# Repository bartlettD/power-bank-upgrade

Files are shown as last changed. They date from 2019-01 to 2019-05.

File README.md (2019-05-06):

# Power Bank Upgrade

A replacement PCB for a cheap single cell power bank.

Designed with KiCad 5.0.2

PDF Schematics, Gerbers and Images are available in the "Docs" directory.

<p float="center">
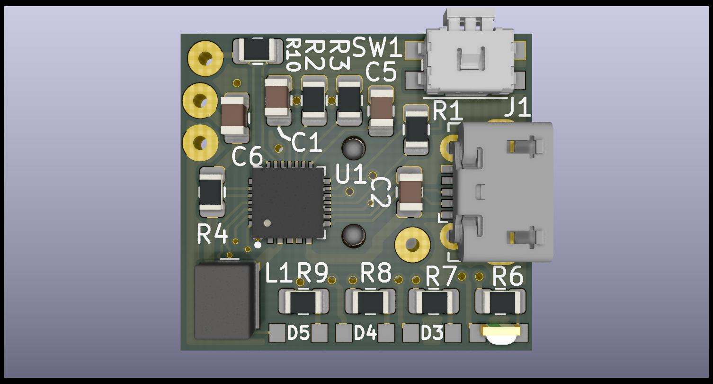
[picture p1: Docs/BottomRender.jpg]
    
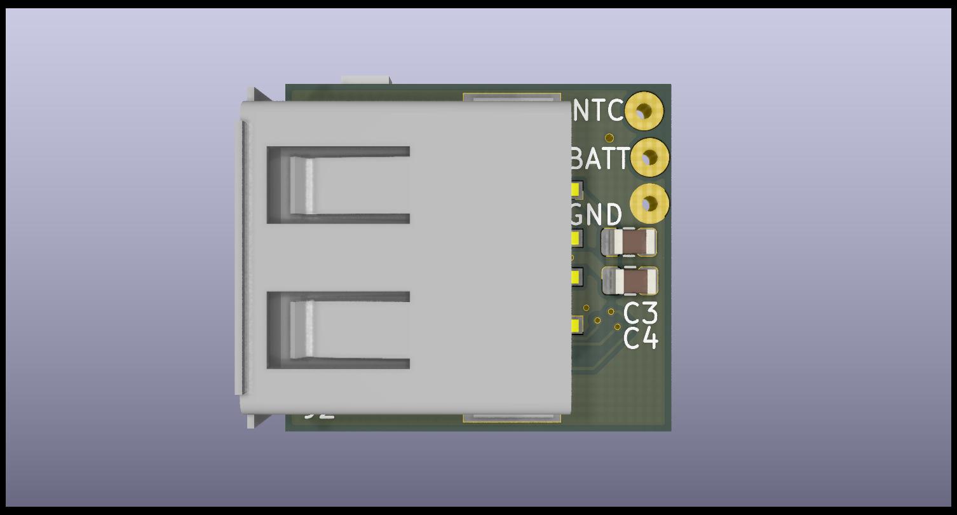
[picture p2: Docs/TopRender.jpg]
    
</p>

## Introduction

This is a single cell, Li-Ion USB Power bank based around an Monolithic Power 
Solutions MP2632B IC.

The board was designed to be broadly compatible with the plastics from a common
model of power bank available from Pound shops except with a few extra features.

## Features

* 3000 mAh LG HG2 Cell. 250% more capacity!
* State of Charge LED indicator.
* Faster Charge and Discharge Currents. (3A)
* Thermistor Thermal Regulation and Shutdown.
* Will actually charge a modern smartphone.

## Licence
The project is licenced under the MIT licence.

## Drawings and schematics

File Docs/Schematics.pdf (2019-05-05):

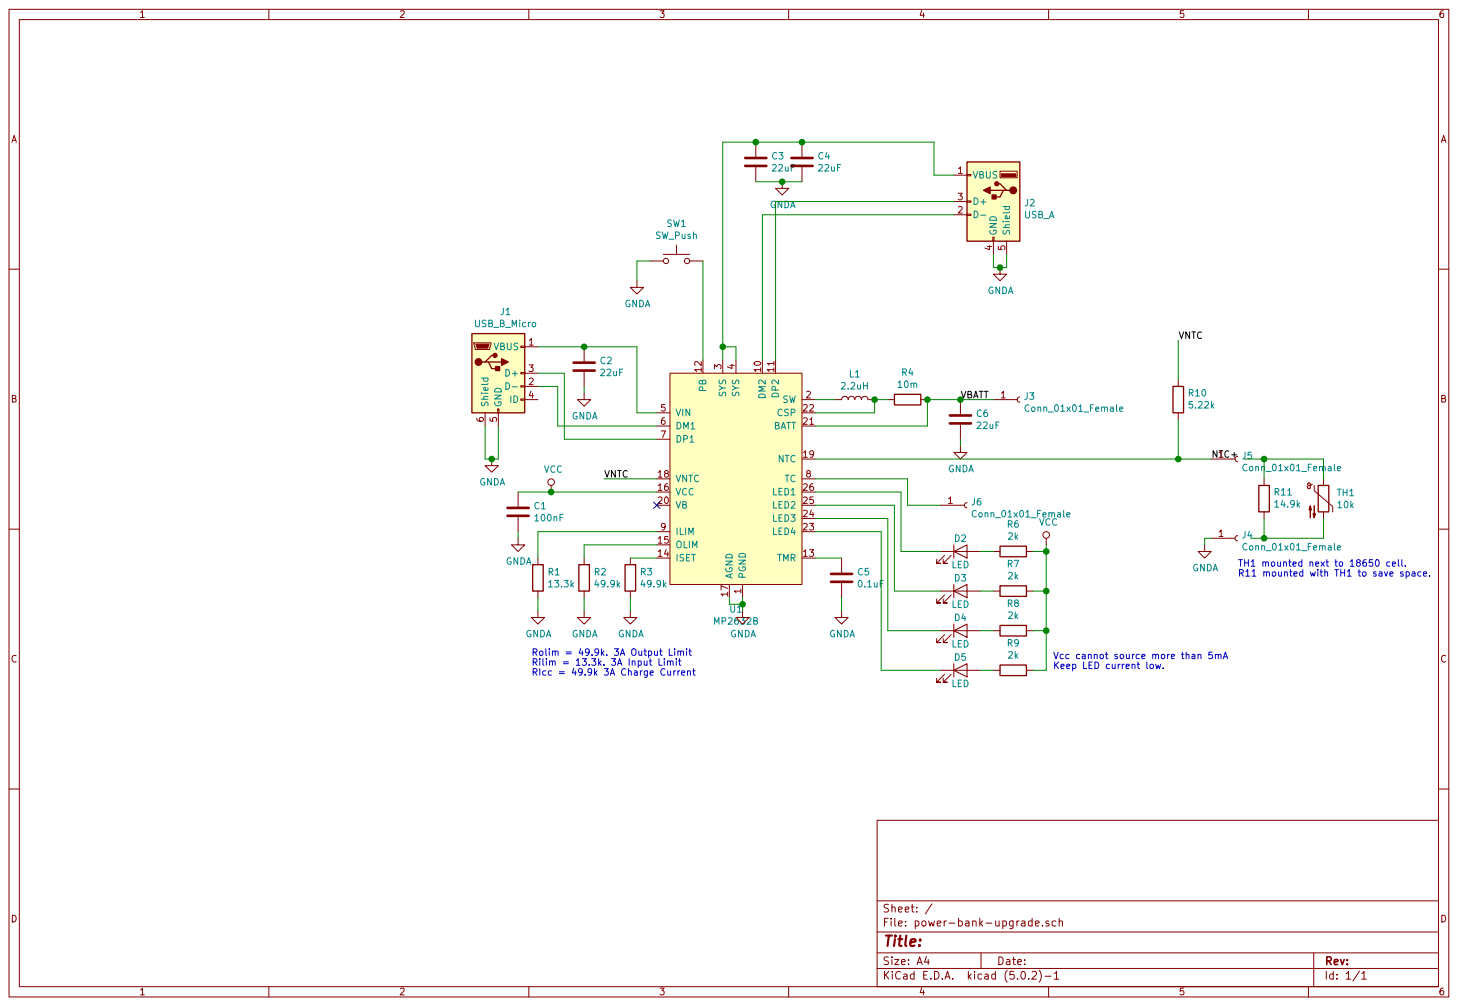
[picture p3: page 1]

1 DM2 10 DP2 11 PB 12 TMR 13 ISET 14 OLIM 15 VCC 16 AGND 17 VNTC 18 NTC 19 SW 2 VB 20 BATT 21 CSP 22

NTC+ Rolim = 49.9k. 3A Output Limit
2k VCC

10k TH1 mounted next to 18650 cell. R11 mounted with TH1 to save space. Vcc cannot source more than 5mA
VCC

File: power-bank-upgrade.sch Sheet: / PGND

Keep LED current low.

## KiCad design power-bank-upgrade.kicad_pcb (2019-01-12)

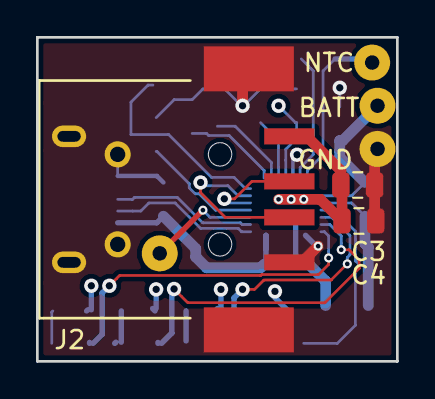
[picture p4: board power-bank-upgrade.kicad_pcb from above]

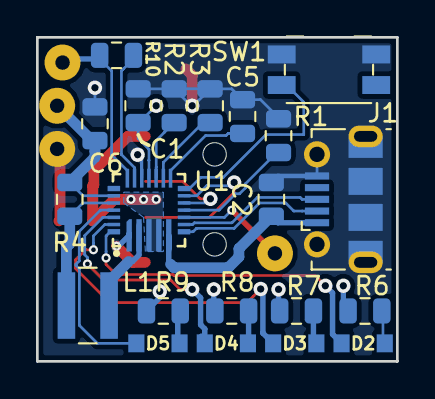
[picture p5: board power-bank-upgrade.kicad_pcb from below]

Board: 4 copper layers, 20.0 x 18.0 mm, 28 parts (21 on the bottom side), 27 nets.

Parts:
BATT: Conn_01x01_Female; SolderWirePad_1x01_Drill0.8mm
C1: 100nF; C_0805_2012Metric
C2, C3, C4: 22uF; C_0805_2012Metric
C5, C6: C; C_0805_2012Metric
D2, D3, D4, D5: LED; APA2107
GND: Conn_01x01_Female; SolderWirePad_1x01_Drill0.8mm
J1: USB_B_Micro; USB_Micro-B_Molex-105017-0001
J2: USB_A; USB_A_Samtec_USB-A-S-F-B-SM2.kicad_mod
J6: Conn_01x01_Female; SolderWirePad_1x01_Drill0.8mm
L1: 2.2uH; L_Wuerth_MAPI-4020
NTC: Conn_01x01_Female; SolderWirePad_1x01_Drill0.8mm
R1: 13.3k; R_0805_2012Metric
R2, R3: 49.9k; R_0805_2012Metric
R4: 10m; R_0805_2012Metric
R6, R7, R8, R9: 210; R_0805_2012Metric
R10: R; R_0805_2012Metric
SW1: SW_Push; Panasonic_EVQPUJ_EVQPUA
U1: MP2632B; MPS_QFN_26_4x4mm_P0.4mm

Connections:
/NTC+: NTC.1, R10.1, U1.19
/VBATT: BATT.1, C6.1, R4.1, U1.21
/VNTC: R10.2, U1.18
GNDA: C1.2, C2.2, C3.2, C4.2, C5.2, C6.2, GND.1, J1.5, J1.6, J2.4, J2.5, R1.2, R2.2, R3.2, SW1.1, U1.1, U1.17
unnamed: C2.1, J1.1, U1.5
unnamed: C3.1, C4.1, J2.1, U1.3, U1.4
unnamed: C5.1, U1.13
unnamed: D2.1, U1.26
unnamed: D2.2, R6.2
unnamed: D3.1, U1.25
unnamed: D3.2, R7.2
unnamed: D4.1, U1.24
unnamed: D4.2, R8.2
unnamed: D5.1, U1.23
unnamed: D5.2, R9.2
unnamed: J1.2, U1.6
unnamed: J1.3, U1.7
unnamed: J2.2, U1.10
unnamed: J2.3, U1.11
unnamed: J6.1, U1.8
unnamed: L1.1, U1.2
unnamed: L1.2, R4.2, U1.22
unnamed: R1.1, U1.9
unnamed: R2.1, U1.15
unnamed: R3.1, U1.14
unnamed: SW1.2, U1.12
VCC: C1.1, R6.1, R7.1, R8.1, R9.1, U1.16

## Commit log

2018-12-06 Created initial project files. Creating MPS MP2632B symbol
    [power-bank-upgrade.kicad_pcb, power-bank-upgrade.sch]
2018-12-06 Added pin no's to symbol
2018-12-06 Started schematic work
    [power-bank-upgrade.sch]
2018-12-06 Started building footprint for MPS battery IC
2018-12-09 Created PCB, started routing. Saving work to try nighly build
    [power-bank-upgrade.kicad_pcb, power-bank-upgrade.sch]
2018-12-09 Abandoning Kicad. Uphill battle
    [power-bank-upgrade.kicad_pcb, power-bank-upgrade.sch]
2018-12-16 Added Samtec USB Type A portm started routing
    [power-bank-upgrade.kicad_pcb, power-bank-upgrade.sch]
2019-01-12 Completed routing for v1. Added fp-info-cache to .gitignore
    [power-bank-upgrade.kicad_pcb, power-bank-upgrade.sch]
2019-02-18 Updated cap values. Increased LED resistor value to reduce current draw. Added NTC thermistor
    [power-bank-upgrade.sch]
2019-05-05 Adding Documentation
    Adding PDF Schematics, Gerbers, 3D Model and Renders
    [power-bank-upgrade-B.Cu.gbr, power-bank-upgrade-B.Mask.gbr, power-bank-upgrade-B.Paste.gbr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]
